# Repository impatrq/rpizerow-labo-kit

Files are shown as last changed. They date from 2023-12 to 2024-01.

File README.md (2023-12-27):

# rpizerow-labo-kit

Este repositorio cuenta con los esquematicos y circuitos impresos del kit de desarrollo basado en la Raspberry Pi Zero W.

Dentro se encuentran:

- Esquematico y PCB del kit
- Lista de materiales en .csv
- Archivos .gbr para mandar a produccion el circuito
- Previsualizacion de los Gerber para ver cada capa que se manda a produccion
- Esquematico en .pdf
- Vistas front y bottom con dimensiones y mascara de componentes en .pdf
- Vista de capa bottom copper en .pdf

Trabajo desarrollado por [Agustin Palmieri Hise](https://github.com/agusplay) y [Fabrizio Carlassara](https://github.com/carlassaraf)

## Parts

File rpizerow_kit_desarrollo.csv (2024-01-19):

Source: | /Users/carlassaraf/Documents/rpizerow-labo-kit/rpizerow_kit_desarrollo.kicad_sch
Date: | 2024 January 18, Thursday 23:51:35
Tool: | Eeschema 7.0.1-0
Generator: | /Applications/KiCad/KiCad.app/Contents/SharedSupport/plugins/bom_csv_grouped_by_value.py
Component Count: | 18
Collated Components:
Item | Qty | Reference(s) | Value | LibPart | Footprint | Datasheet | DNP
1 | 1 | BZ1 | Buzzer | Device:Buzzer | Buzzer_Beeper:Buzzer_12x9.5RM7.6 | ~
2 | 1 | D1 | LED_RKGB | Device:LED_RKGB |  | ~
3 | 1 | J1 | Conector USB | Connector:Conn_01x05_Pin | Connector_PinHeader_2.54mm:PinHeader_1x05_P2.54mm_Horizontal | ~
4 | 1 | J2 | Screw_Terminal_01x02 | Connector:Screw_Terminal_01x02 | TerminalBlock_Phoenix:TerminalBlock_Phoenix_MKDS-1,5-2-5.08_1x02_P5.08mm_Horizontal | ~
5 | 1 | LDR1 | 10K | Sensor_Optical:A9050 | OptoDevice:R_LDR_5.0x4.1mm_P3mm_Vertical | http://cdn-reichelt.de/documents/datenblatt/A500/A90xxxx%23PE.pdf
6 | 1 | NTC1 | 10K | Device:Thermistor | Resistor_THT:R_Axial_DIN0204_L3.6mm_D1.6mm_P2.54mm_Vertical | ~
7 | 2 | R1, R2 | 10k | Device:R | Resistor_THT:R_Axial_DIN0207_L6.3mm_D2.5mm_P7.62mm_Horizontal | ~
8 | 3 | R3, R4, R5 | 220R | Device:R | Resistor_THT:R_Axial_DIN0207_L6.3mm_D2.5mm_P7.62mm_Horizontal | ~
9 | 1 | R6 | 10K | Device:R | Resistor_THT:R_Axial_DIN0207_L6.3mm_D2.5mm_P7.62mm_Horizontal | ~
10 | 1 | RV1 | 10K | Device:R_Potentiometer | Potentiometer_THT:Potentiometer_Bourns_3386F_Vertical | ~
11 | 1 | SW1 | SW_DIP_x01 | Switch:SW_DIP_x01 | Button_Switch_THT:SW_PUSH_6mm_H13mm | ~
12 | 1 | U1 | RPizeroW | Raspberrt Pi Zero:RPi_GPIO | Module:Raspberry_Pi_Zero_Socketed_THT_FaceDown_MountingHoles
13 | 1 | U2 | ADS1115IDGS | Analog_ADC:ADS1115IDGS | Connector_PinHeader_2.54mm:PinHeader_1x10_P2.54mm_Vertical | http://www.ti.com/lit/ds/symlink/ads1113.pdf
14 | 1 | U3 | BMP180 | Connector:Conn_01x04_Pin | Connector_PinHeader_2.54mm:PinHeader_1x04_P2.54mm_Vertical | ~
15 | 1 | U4 | TM1637 | Connector:Conn_01x04_Pin | TM1637:TM1637 | ~

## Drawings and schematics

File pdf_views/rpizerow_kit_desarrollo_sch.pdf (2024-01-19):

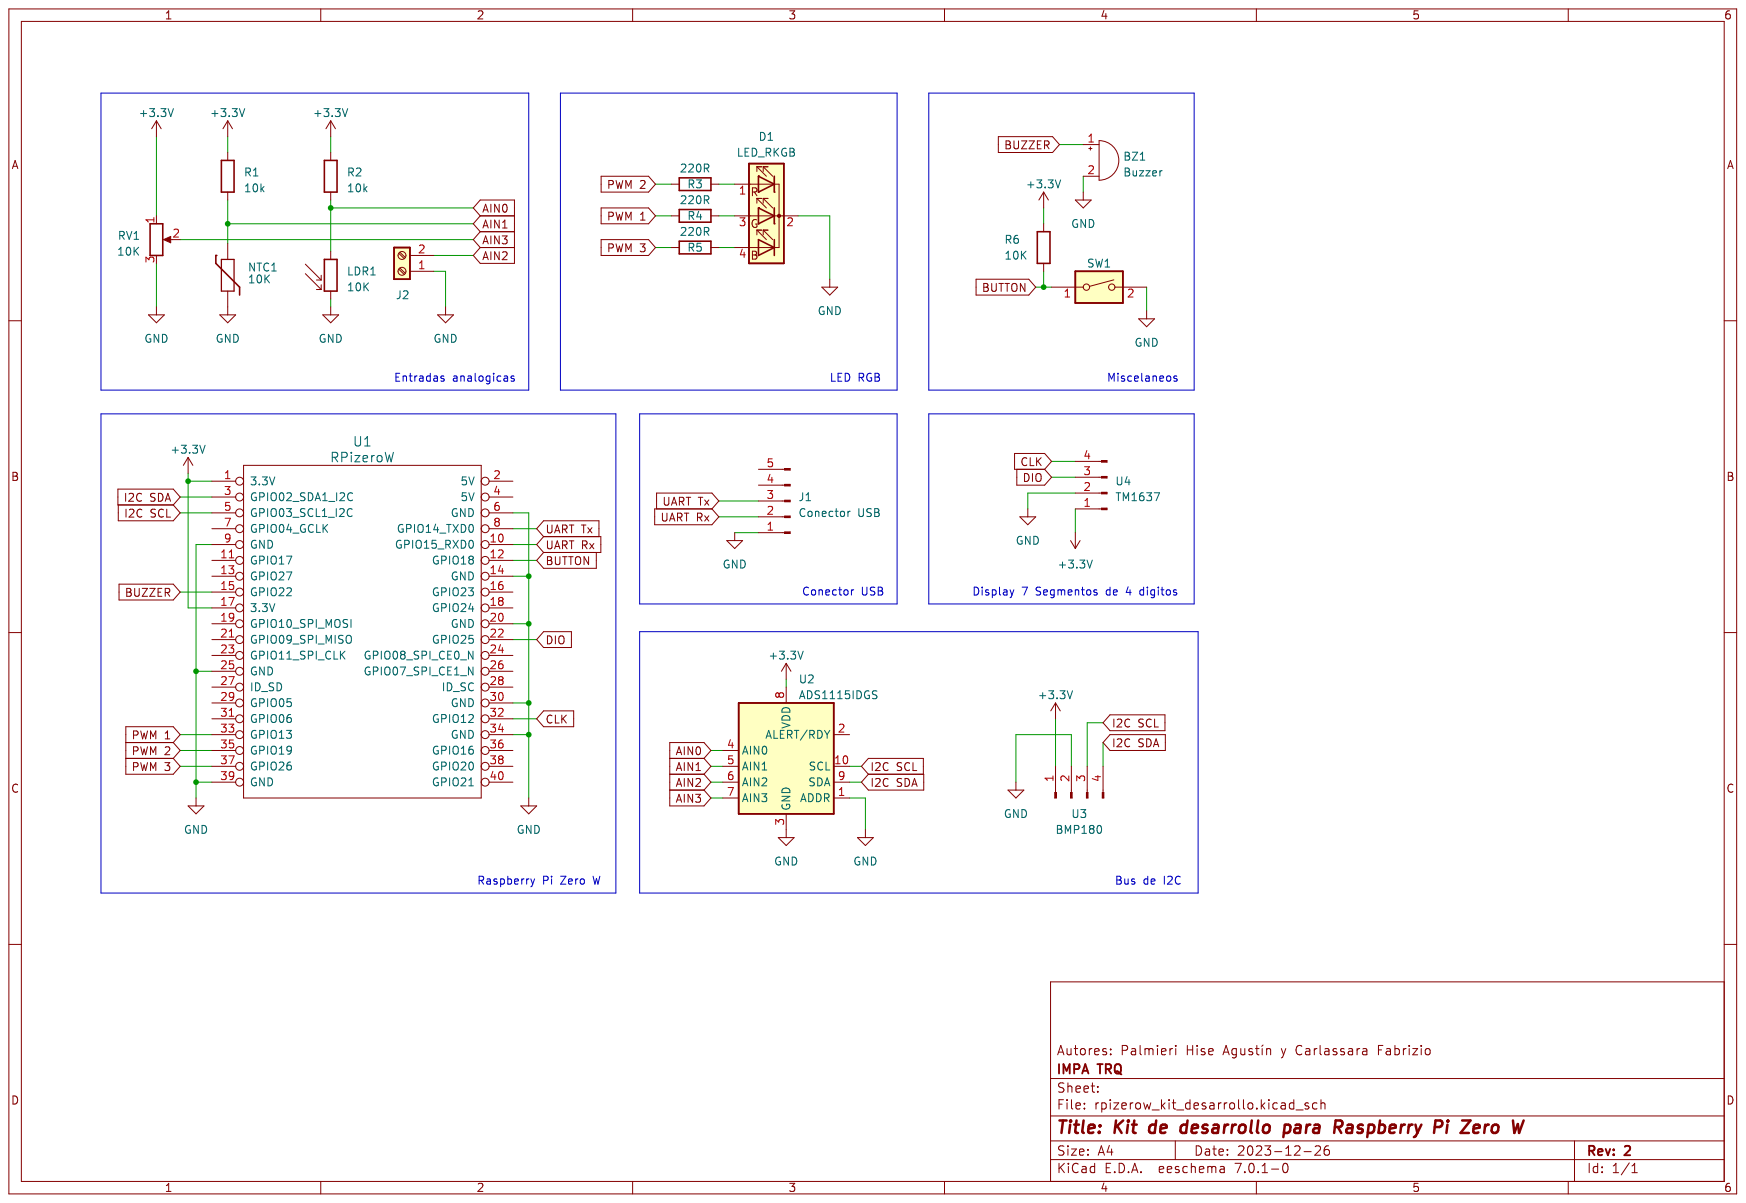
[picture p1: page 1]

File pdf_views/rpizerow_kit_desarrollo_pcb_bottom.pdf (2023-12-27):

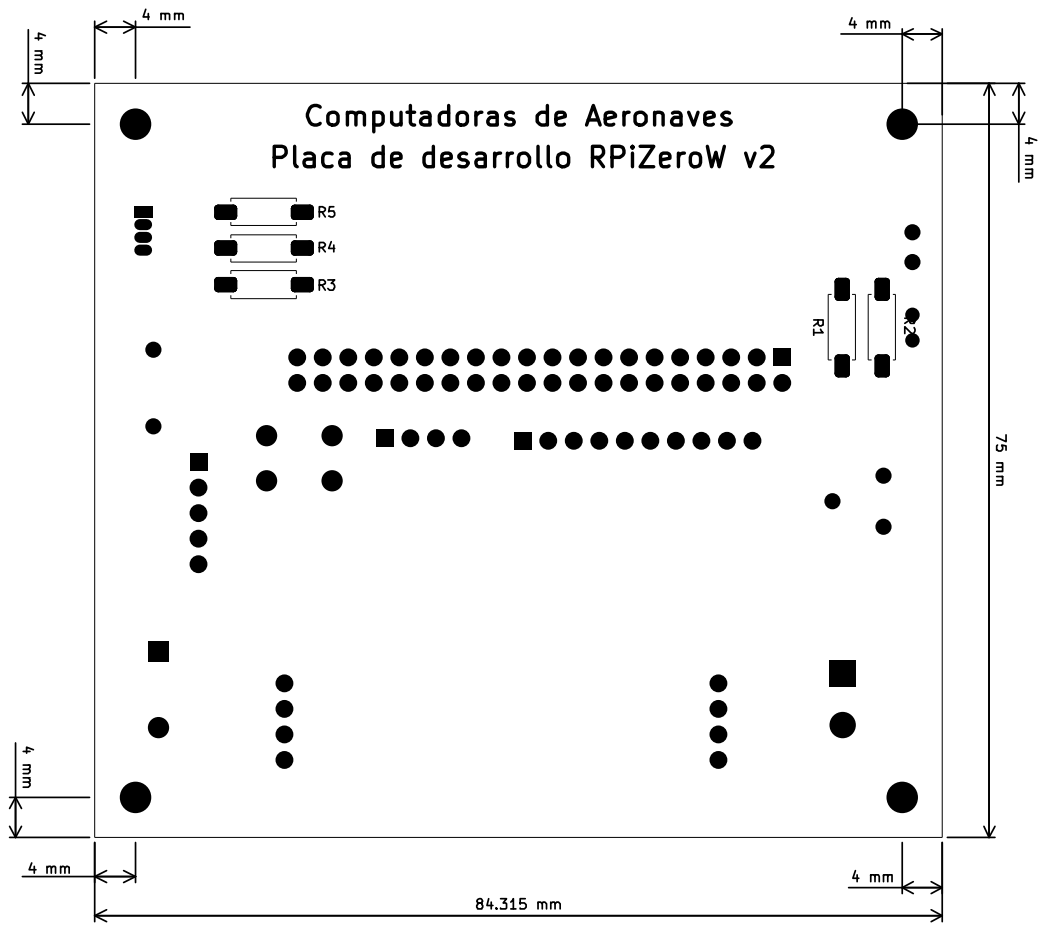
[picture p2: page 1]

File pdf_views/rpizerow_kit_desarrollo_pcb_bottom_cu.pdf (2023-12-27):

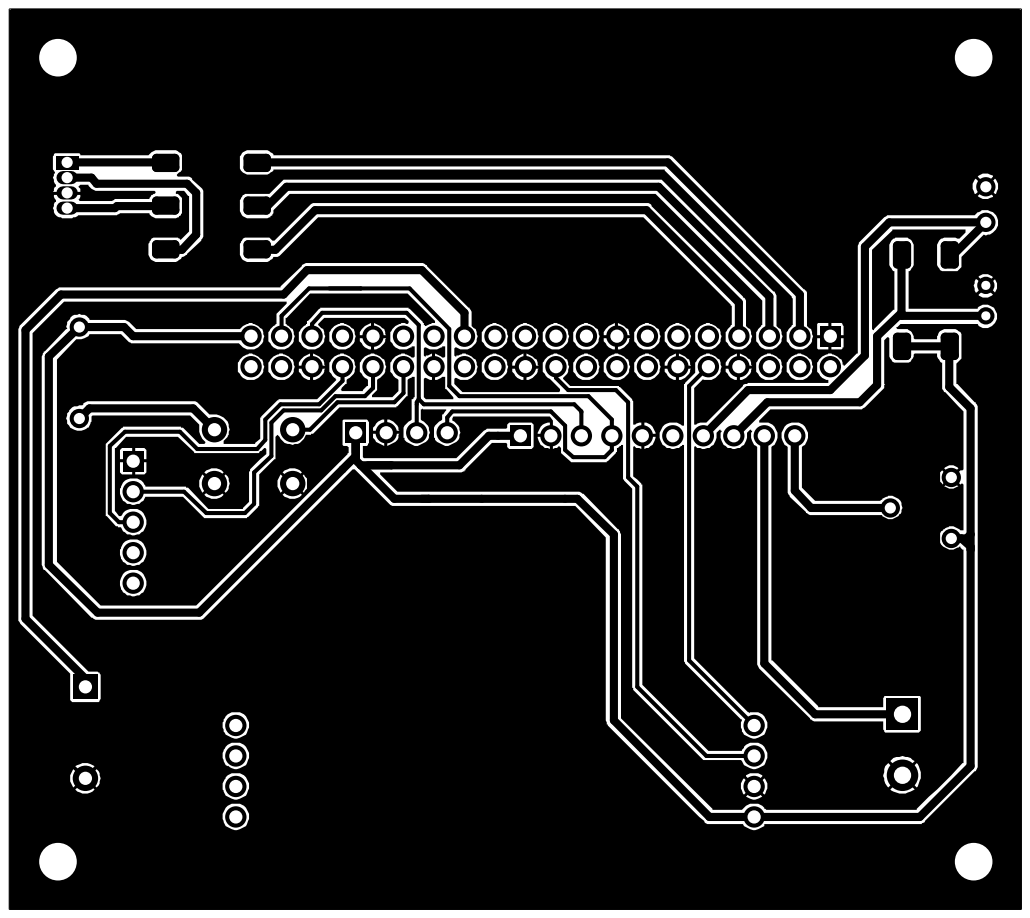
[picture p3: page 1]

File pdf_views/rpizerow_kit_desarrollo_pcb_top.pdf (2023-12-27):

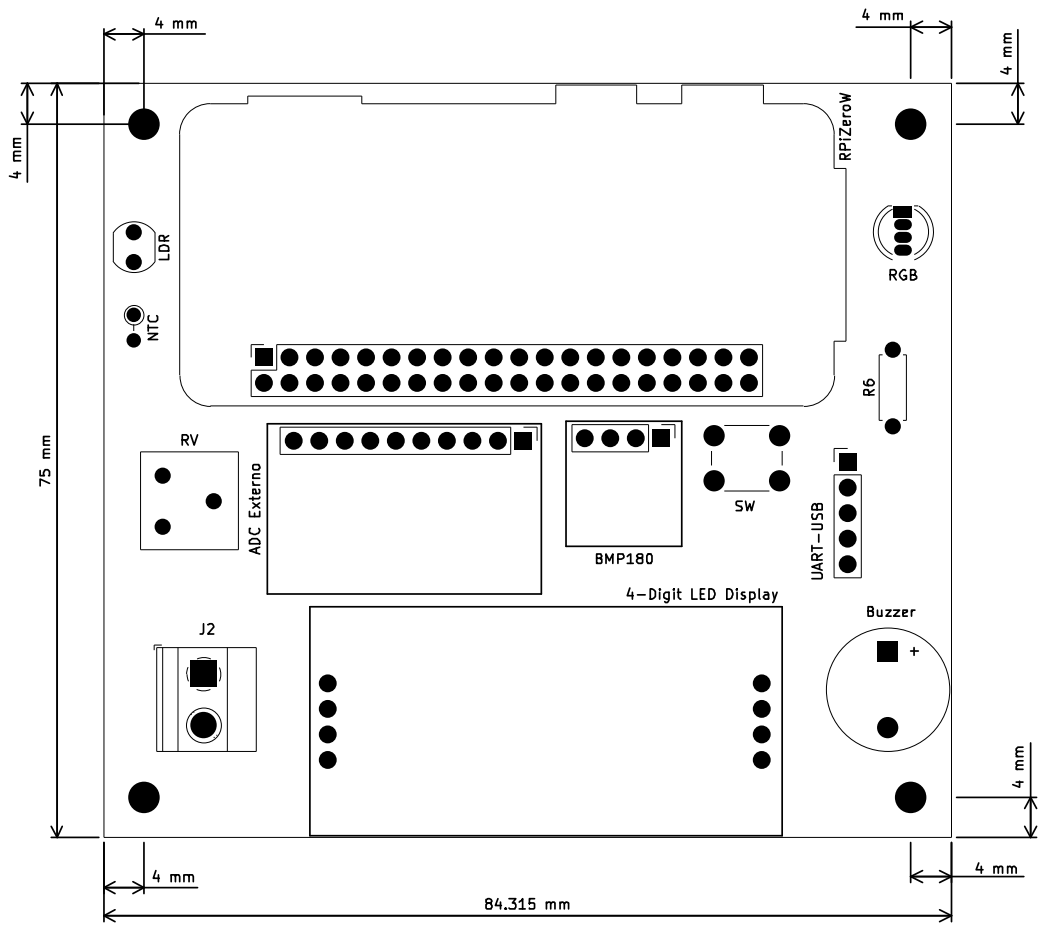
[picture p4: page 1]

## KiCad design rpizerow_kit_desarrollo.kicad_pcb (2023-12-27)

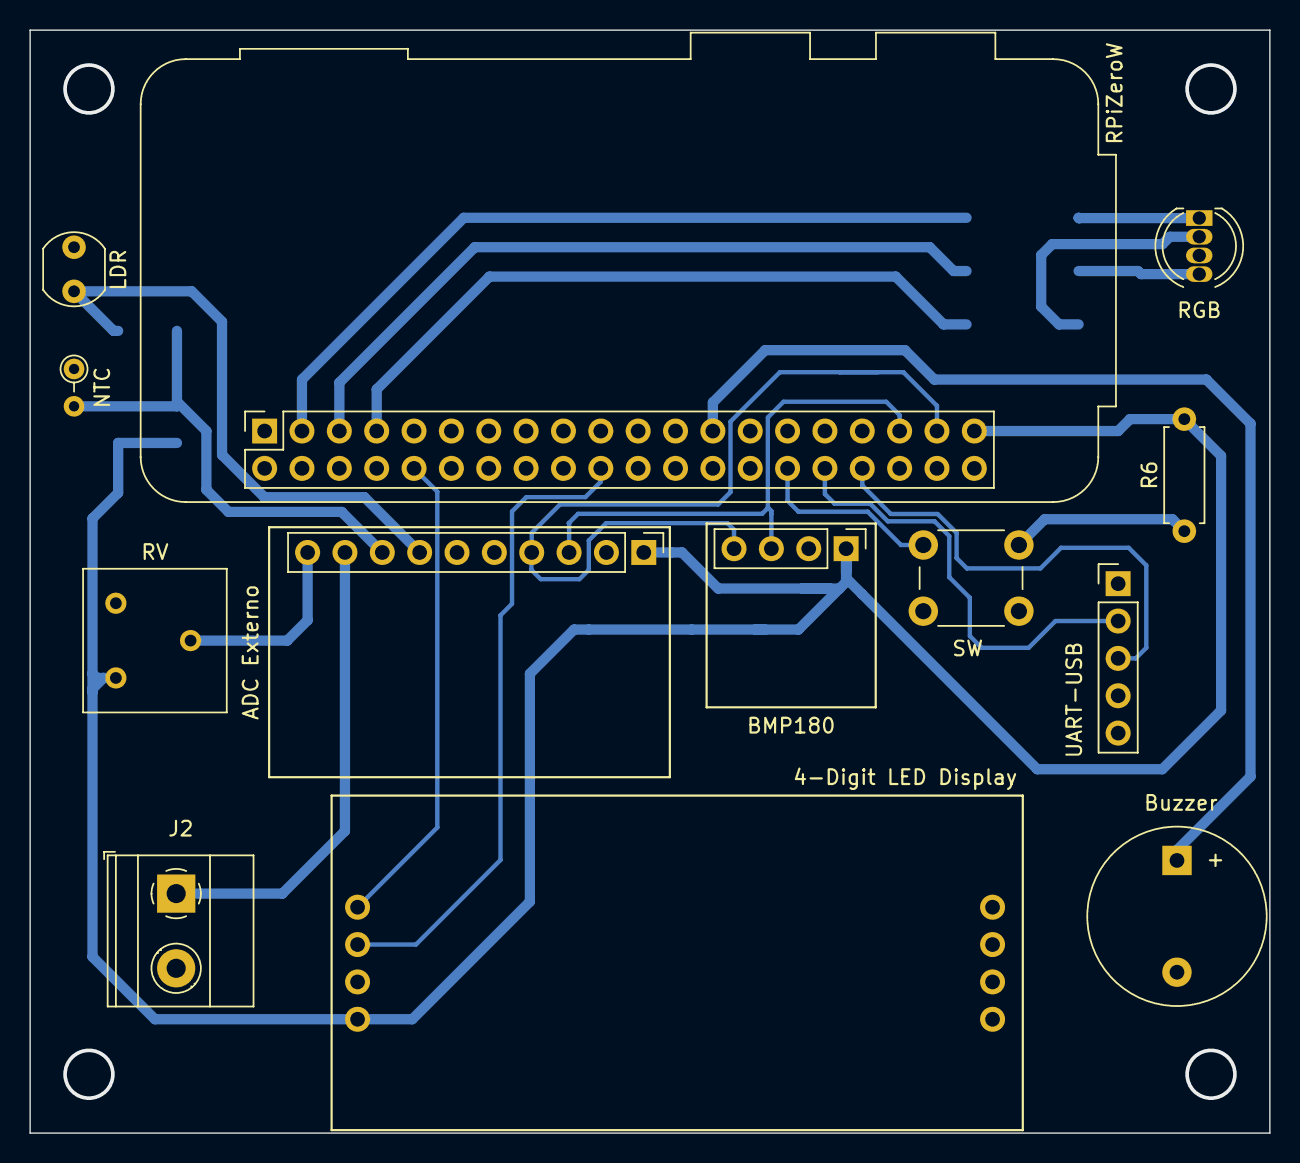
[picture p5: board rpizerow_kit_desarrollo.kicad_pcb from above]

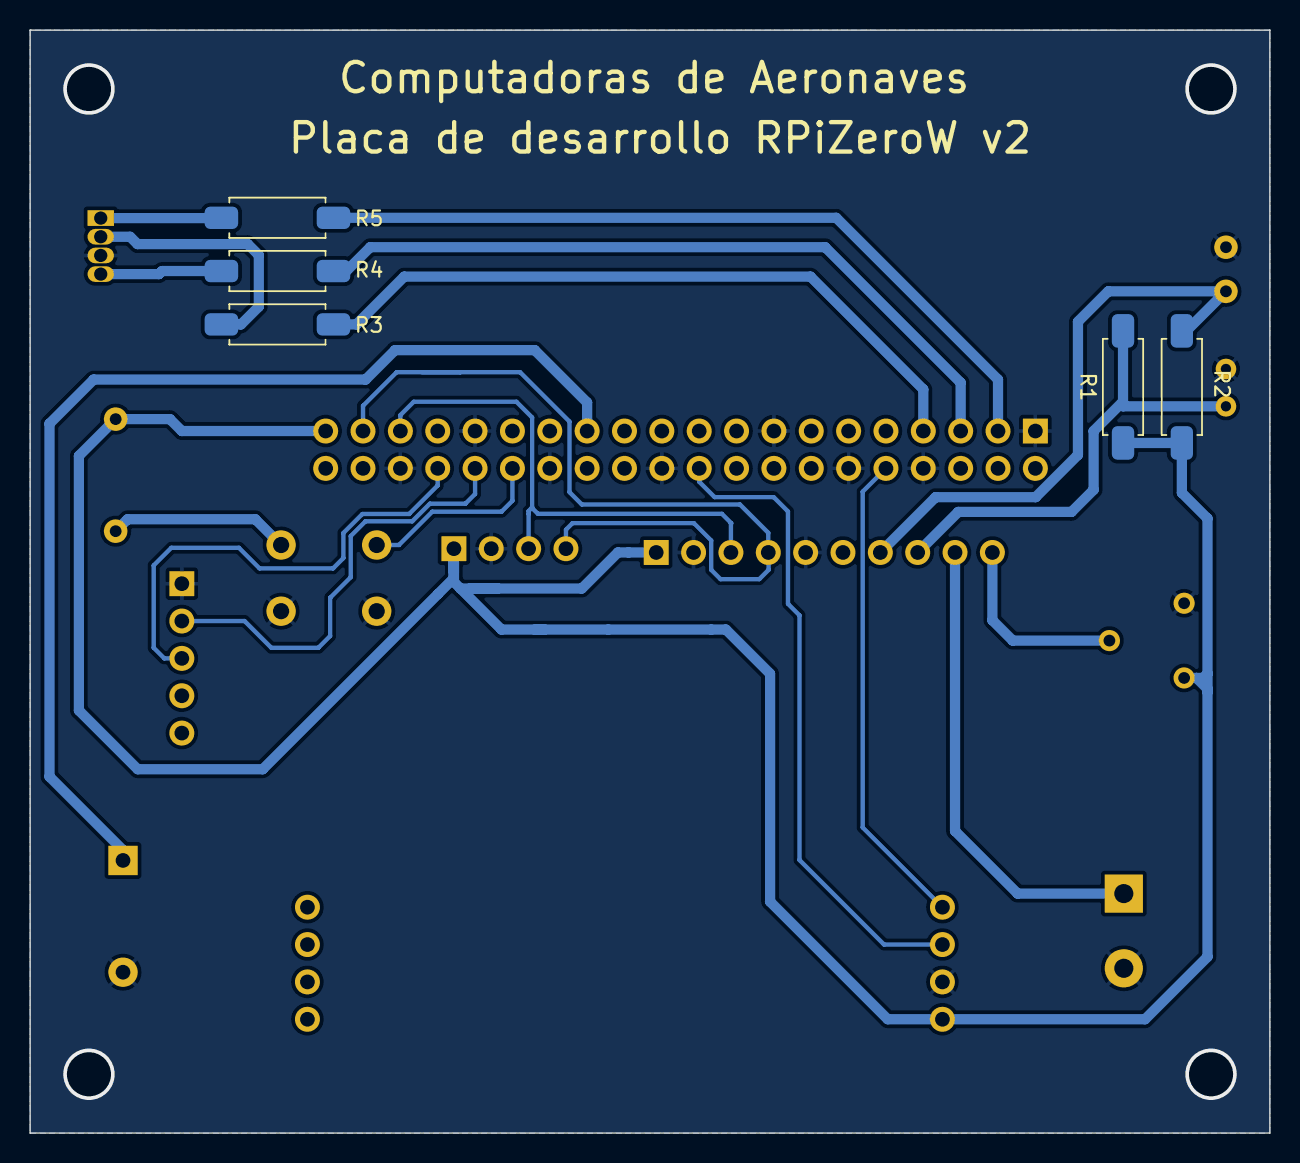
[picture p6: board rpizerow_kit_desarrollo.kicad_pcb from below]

Board: 2 copper layers, 84.3 x 75.0 mm, 18 parts (5 on the bottom side), 20 nets.

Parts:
4-Digit LED Display: TM1637
ADC Externo: ADS1115IDGS; PinHeader_1x10_P2.54mm_Vertical
BMP180: BMP 280; PinHeader_1x04_P2.54mm_Vertical
Buzzer: Buzzer; Buzzer_12x9.5RM7.6
J2: Screw_Terminal_01x02; TerminalBlock_Phoenix_MKDS-1,5-2-5.08_1x02_P5.08mm_Horizont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
LDR: A9050; R_LDR_5.0x4.1mm_P3mm_Vertical
NTC: Thermistor; R_Axial_DIN0204_L3.6mm_D1.6mm_P2.54mm_Vertical
R1, R2: 10k; R_Axial_DIN0207_L6.3mm_D2.5mm_P7.62mm_Horizontal
R3, R4, R5: 220; R_Axial_DIN0207_L6.3mm_D2.5mm_P7.62mm_Horizontal
R6: R; R_Axial_DIN0207_L6.3mm_D2.5mm_P7.62mm_Horizontal
RGB: LED_RGB; LED_D5.0mm-4_RGB
RPiZeroW: RPi_GPIO; Raspberry_Pi_Zero_Socketed_THT_FaceDown_MountingHoles
RV: R_Potentiometer; Potentiometer_Bourns_3386F_Vertical
SW: SW_DIP_x01; SW_PUSH_6mm_H13mm
UART-USB: Conector USB; PinHeader_1x05_P2.54mm_Vertical

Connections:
+3.3V: 4-Digit LED Display.1, ADC Externo.8 (VDD), BMP180.1, R1.1, R2.1, R6.2, RPiZeroW.1 (3.3V), RPiZeroW.17 (3.3V), RV.1
CLK: 4-Digit LED Display.4, RPiZeroW.32 (GPIO12)
DIO: 4-Digit LED Display.3, RPiZeroW.22 (GPIO25)
GND: 4-Digit LED Display.2, ADC Externo.1 (ADDR), ADC Externo.3 (GND), BMP180.2, Buzzer.2 (+), J2.1, LDR.2, NTC.1, RGB.2, RPiZeroW.6 (GND), RPiZeroW.9 (GND), RPiZeroW.14 (GND), RPiZeroW.20 (GND), RPiZeroW.25 (GND), RPiZeroW.30 (GND), RPiZeroW.34 (GND), RPiZeroW.39 (GND), RV.3, SW.2, UART-USB.1
I2C SCL: ADC Externo.10 (SCL), BMP180.3, RPiZeroW.5 (GPIO03_SCL1_I2C)
I2C SDA: ADC Externo.9 (SDA), BMP180.4, RPiZeroW.3 (GPIO02_SDA1_I2C)
I/O 12: Buzzer.1 (-), RPiZeroW.15 (GPIO22)
I/O 13: R6.1, RPiZeroW.12 (GPIO18), SW.1
unnamed: R3.2, RGB.3
unnamed: R4.2, RGB.1 (BA)
unnamed: R5.2, RGB.4 (RK)
unnamed: ADC Externo.6 (AIN2), J2.2
unnamed: ADC Externo.4 (AIN0), LDR.1, R2.2
unnamed: ADC Externo.5 (AIN1), NTC.2, R1.2
unnamed: ADC Externo.7 (AIN3), RV.2
PWM 1: R3.1, RPiZeroW.33 (GPIO13)
PWM 2: R4.1, RPiZeroW.35 (GPIO19)
PWM 3: R5.1, RPiZeroW.37 (GPIO26)
UART Rx: RPiZeroW.10 (GPIO15_RXD0), UART-USB.2
UART Tx: RPiZeroW.8 (GPIO14_TXD0), UART-USB.3

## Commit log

2023-12-27 esquematico v2
    [rpizerow_kit_desarrollo.kicad_sch]
2023-12-27 pcb version 2
    [rpizerow_kit_desarrollo.kicad_pcb]
2023-12-27 gerbers para mandar a produccion
    [rpizerow_kit_desarrollo-B_Cu.gbr, rpizerow_kit_desarrollo-B_Mask.gbr, rpizerow_kit_desarrollo-B_Paste.gbr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]
2023-12-27 inicializacion de proyecto
2023-12-27 agrego huella a rgb
    [rpizerow_kit_desarrollo.kicad_sch]
2023-12-27 actualizo por huella de rgb
    [rpizerow_kit_desarrollo.csv]
2023-12-27 agrego vistas de los gerbers
2023-12-27 vistas de esquematico y pcb en pdf
2024-01-19 corrijo RGB
    [rpizerow_kit_desarrollo.kicad_sch]
2024-01-19 corrijo etiquetas
    [rpizerow_kit_desarrollo.kicad_sch]
2024-01-19 corrijo valor de resistencias
    [rpizerow_kit_desarrollo.kicad_sch]
2024-01-19 corrijo bom
    [rpizerow_kit_desarrollo.csv]
